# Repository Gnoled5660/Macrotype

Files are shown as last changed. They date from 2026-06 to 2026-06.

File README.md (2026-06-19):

# Macrotype
Macropad_with_Case_2026-Jun-15_12-51-55PM-000_CustomizedView37122516277_png

# Description
This is a fully custom wireless hot swappable macropad with a custom Microcontroller. It has a total of nine fully custom programmable keyswitches and a rotary encoder as well as a 0.91 OLED display. It still remains pretty compact, while having that many components. It's size is approximately 10x6.8x1.6cm. There is a LiPo 3.7V Battery built in, but if you want to charge it, you can simply charge the battery via the USB-C receptacle. The macropad has an IC charger built in. If it is connected to the USB-C port, then the nRF52840 MCU chip, will be directly powered by the external power source, while the battery is being charged. However, if it is not connected to an external power supply, then the chip will be powered by the battery.

# Motivation
I have always wanted to design my own macropad, as it can be quite useful. I wanted to challenge myself a little bit, which is why I didn't choose a regular microcontroller and designed the entire board myself. 

# Assembling the macropad
It is quite straight forward to assemble everything. As the PCB will be preassembled by JLCPCB, since there are many components that cannot be hand soldered, there is not much to do on the soldering part. It is only necessary to solder the display and the rotary encoder onto the PCB and connect the Battery with the socket. There are four mounting holes on the PCB, that are used to screw screws onto the CAD model. For this project, you only need four M2 screws. It is also recommended to use heated threat inserts, to guarentee more grip.

# Schematic and Components
The main component is the nRF52840, a relatively cheap chip, that is capable of bluetooth low energy. This chip functions as the main processing unit, to handle all the actions that can be done with the board. Another important component is the BQ24074, it is an IC charger that can charge the battery, while still letting power to the MCU. As the battery is a 3.7V LiPo, the voltage always varies between 3.3V and 4.0V. Thats why there is also a Low Dropout Regulator, that convert the voltage to 3.3V.

Bildschirmfoto 2026-06-15 um 15 30 08

Using this reference provided by nordic semiconductors, I was able to draw the schematic around the chip.

Bildschirmfoto 2026-06-19 um 12 18 31

# PCB
The PCB is a 4 layer PCB, with the first and fourth layer function as signal transmitting layers. The second layer is a big Ground plane and the third layer is a hybrid layer with signal tracks and Ground planes. The most crucial part of the PCB is the radio frequency part. This part cannot have any tracks or Ground planes above or under it, as any distrubances might change the frequency.

Bildschirmfoto 2026-06-15 um 15 33 07

Bildschirmfoto 2026-06-15 um 15 30 40

Bildschirmfoto 2026-06-17 um 20 18 41

Bildschirmfoto 2026-06-17 um 20 19 51

# Firmware 
To flash the nRF52840 chip, you have to use a bootloader and connect it physically to the pin sockets on the board. There is a row with SWD sockets. Connect it to these rows and flash the Firmware onto it. You can find it in the folder Firmware. Afterwards, you can simply connect the chip via the USB-C port to a computer and upload the uf2 file, which contains all the keyboard settings and drag the files onto the chip. The keyboard firmware was built with ZMK.

# Firmware setup
The firmware was built with ZMK. After following the guide of ZMK of how to setup your own ZMK configuration GitHub repo, you have to change the board informations according to your needs. My custom Macropad includes having a rotary encoder, display and a 3x3 Matrix switches. You can find the configurations in detail in the ZMK config file.

# Case
The case consists of two different parts. The bottom part has four holes, where heated threat inserts can be inserted. There is a rectangle that stands out a little bit, so that it can be pressed in to the other part.

Bildschirmfoto 2026-06-17 um 23 51 36

Bildschirmfoto 2026-06-17 um 23 53 58

Copy of fallout_zine_template-7

# BOM
|Reference |Qty |Links |Value|Footprint|Description |Price |
|---|---|---|-----|---|---|---|
|Crystal |1 |https://jlcpcb.com |32.768kHz|Crystal:Crystal_SMD_3215-2Pin_3.2x1.5mm|Two pin crystal  |See below|
|Crystal |1 |https://jlcpcb.com |32MHz|Crystal:Crystal_SMD_2016-4Pin_2.0x1.6mm|Two pin crystal  |See below|
|Low Dropout Regulator|1 |https://jlcpcb.com |MCP1700T-3302E_TT|MCP1700T-3302E_TT:SOT95P237X112-3N|Pwr Sply Func,Voltage Regulator,LDO,SOT-23,PD 369.6mW,VO 3.3V,Regline +/-0.75%/V &#124; Microchip Technology Inc. MCP1700T-3302E/TT|See below|
|IC Charger |1 |https://jlcpcb.com |BQ24074RGTR|BQ24074RGTR:QFN50P300X300X100-17N|Standalone 1-cell 1.5-A linear battery charger, Power Path, 4.2-V VBAT, 10.5-V OVP and 4.4-V VOUT|See below|
|nRF52840 |1 |https://jlcpcb.com |NRF52840-QIAA-R|footprints:AQFN-73-1EP_7x7mm_P0.5mm_NRF52840-custom|IC RF TxRx + MCU 802.15.4, Bluetooth Bluetooth v5.0, Thread, Zigbee® 2.4GHz 73-VFQFN Dual Rows, Exposed Pad|See below|
|Rotary Encoder |1 |https://jlcpcb.com |RotaryEncoder_Switch|Rotary_Encoder:RotaryEncoder_Alps_EC11E-Switch_Vertical_H20mm|Rotary encoder, dual channel, incremental quadrate outputs, with switch|See below|
|Button |1 |https://jlcpcb.com |SW_Push|Button_Switch_SMD:SW_Push_1P1T_NO_CK_KMR2|Push button switch, generic, two pins|See below|
|Keyswitch |9 |https://jlcpcb.com |Keyswitch|Switch_Keyboard_Hotswap_Kailh:SW_Hotswap_Kailh_MX|Push button switch, normally open, two pins, 45° tilted|See below|
|Resistor |2 |https://jlcpcb.com |5.1k |Resistor_SMD:R_0402_1005Metric|Resistor |See below|
|Resistor |3 |https://jlcpcb.com |10k  |Resistor_SMD:R_0402_1005Metric|Resistor |See below|
|Resistor |1 |https://jlcpcb.com |47k  |Resistor_SMD:R_0402_1005Metric|Resistor |See below|
|Resistor |1 |https://jlcpcb.com |0 |Resistor_SMD:R_0402_1005Metric|Resistor |See below|
|Resistor |1 |https://jlcpcb.com |5.9k |Resistor_SMD:R_0402_1005Metric|Resistor |See below|
|Resistor |1 |https://jlcpcb.com |3.0k |Resistor_SMD:R_0402_1005Metric|Resistor |See below|
|Resistor |2 |https://jlcpcb.com |1.5k |Resistor_SMD:R_0402_1005Metric|Resistor |See below|
|Inductor |1 |https://jlcpcb.com |4.7nH|Inductor_SMD:L_0402_1005Metric|Inductor |See below|
|USB-C Receptacle |1 |https://jlcpcb.com |TYPE-C-31-M-12|TYPE-C-31-M-12:HRO_TYPE-C-31-M-12|USB Connectors 24 Receptacle 1 8.94*7.3mm RoHS|See below|
|JST Socket |1 |https://jlcpcb.com |Conn_01x02_Socket|Connector_JST:JST_PH_S2B-PH-K_1x02_P2.00mm_Horizontal|Generic connector, single row, 01x02, script generated|See below|
|LED |2 |https://jlcpcb.com |LED  |LED_SMD:LED_0603_1608Metric|Light emitting diode|See below|
|Unpolarized Capcitor|1 |https://jlcpcb.com |820pF|Capacitor_SMD:C_0402_1005Metric|Unpolarized capacitor|See below|
|Unpolarized Capcitor|1 |https://jlcpcb.com |1.5pF|Capacitor_SMD:C_0402_1005Metric|Unpolarized capacitor|See below|
|Unpolarized Capcitor|1 |https://jlcpcb.com |0.5pF|Capacitor_SMD:C_0402_1005Metric|Unpolarized capacitor|See below|
|Unpolarized Capcitor|1 |https://jlcpcb.com |0.8pF|Capacitor_SMD:C_0402_1005Metric|Unpolarized capacitor|See below|
|Unpolarized Capcitor|1 |https://jlcpcb.com |100pF|Capacitor_SMD:C_0402_1005Metric|Unpolarized capacitor|See below|
|Unpolarized Capcitor|2 |https://jlcpcb.com |N.C. |Capacitor_SMD:C_0402_1005Metric|Unpolarized capacitor|See below|
|Unpolarized Capcitor|1 |https://jlcpcb.com |1.0uF|Capacitor_SMD:C_0603_1608Metric|Unpolarized capacitor|See below|
|Unpolarized Capcitor|4 |https://jlcpcb.com |1uF  |Capacitor_SMD:C_0603_1608Metric|Unpolarized capacitor|See below|
|Unpolarized Capcitor|3 |https://jlcpcb.com |100nF|Capacitor_SMD:C_0402_1005Metric|Unpolarized capacitor|See below|
|Unpolarized Capcitor|4 |https://jlcpcb.com |12pF |Capacitor_SMD:C_0402_1005Metric|Unpolarized capacitor|See below|
|Unpolarized Capcitor|4 |https://jlcpcb.com |4.7uF|Capacitor_SMD:C_0603_1608Metric|Unpolarized capacitor|See below|
|0.91 Display |1 |https://www.roboter-bausatz.de/p/0.91-oled-display-blau-128-32-ssd1306-i2c-modul-fuer-arduino-raspberry-pi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 | | |Oled Display 128x32|4 |
|Hot Swappable Sockets|50 |https://amazon.com | | |Kailh CPG151101S11 Hot Swappable PCB Socket|10 |
|PCB with all Components|1 |https://jlcpcb.com | | |5x PCB fully assembled|110 |
|Filament | | | | | 40g | 0.5 |
|total | | | | | |124 |

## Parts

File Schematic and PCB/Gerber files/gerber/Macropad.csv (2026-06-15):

Id | Designator | Footprint | Quantity | Designation | Supplier and ref
1 |  |  | 1
2 | C1, C17, C19, C20 | C_0603_1608Metric | 4 | 4.7uF
3 | C2, C3, C11, C12 | C_0402_1005Metric | 4 | 12pF
4 | C4, C10, C23 | C_0402_1005Metric | 3 | 100nF
5 | C5, C18, C21, C22 | C_0603_1608Metric | 4 | 1uF
6 | C6 | C_0603_1608Metric | 1 | 1.0uF
7 | C7, C9 | C_0402_1005Metric | 2 | N.C.
8 | C8 | C_0402_1005Metric | 1 | 100pF
9 | C13 | C_0402_1005Metric | 1 | 0.8pF
10 | C14 | C_0402_1005Metric | 1 | 0.5pF
11 | C15 | C_0402_1005Metric | 1 | 1.5pF
12 | C16 | C_0402_1005Metric | 1 | 820pF
13 | D10, D11 | LED_0603_1608Metric | 2 | LED
14 | Display1 | PinHeader_1x04_P2.54mm_Vertical | 1 | Conn_01x04_Socket
15 | J1 | JST_PH_S2B-PH-K_1x02_P2.00mm_Horizontal | 1 | Conn_01x02_Socket
16 | J2 | HRO_TYPE-C-31-M-12 | 1 | TYPE-C-31-M-12
17 | L1 | L_0402_1005Metric | 1 | 4.7nH
18 | MCU_flash1 | PinHeader_1x05_P2.54mm_Vertical | 1 | Conn_01x05_Socket
19 | R1, R2 | R_0402_1005Metric | 2 | 1.5k
20 | R3 | R_0402_1005Metric | 1 | 3.0k
21 | R4 | R_0402_1005Metric | 1 | 5.9k
22 | R5 | R_0402_1005Metric | 1 | 0
23 | R6 | R_0402_1005Metric | 1 | 47k
24 | R7, R9, R10 | R_0402_1005Metric | 3 | 10k
25 | R11, R12 | R_0402_1005Metric | 2 | 5.1k
26 | SW1, SW2, SW3, SW4, SW5, SW6, SW7, SW8, SW9 | SW_Hotswap_Kailh_MX | 9 | Keyswitch
27 | SW10 | SW_Push_1P1T_NO_CK_KMR2 | 1 | SW_Push
28 | SW11 | RotaryEncoder_Alps_EC11E-Switch_Vertical_H20mm | 1 | RotaryEncoder_Switch
29 | U1 | AQFN-73-1EP_7x7mm_P0.5mm_NRF52840-custom | 1 | NRF52840-QIAA-R
30 | U2 | QFN50P300X300X100-17N | 1 | BQ24074RGTR
31 | VR1 | SOT95P237X112-3N | 1 | MCP1700T-3302E_TT
32 | X1 | Crystal_SMD_2016-4Pin_2.0x1.6mm | 1 | 32MHz
33 | X2 | Crystal_SMD_3215-2Pin_3.2x1.5mm | 1 | 32.768kHz

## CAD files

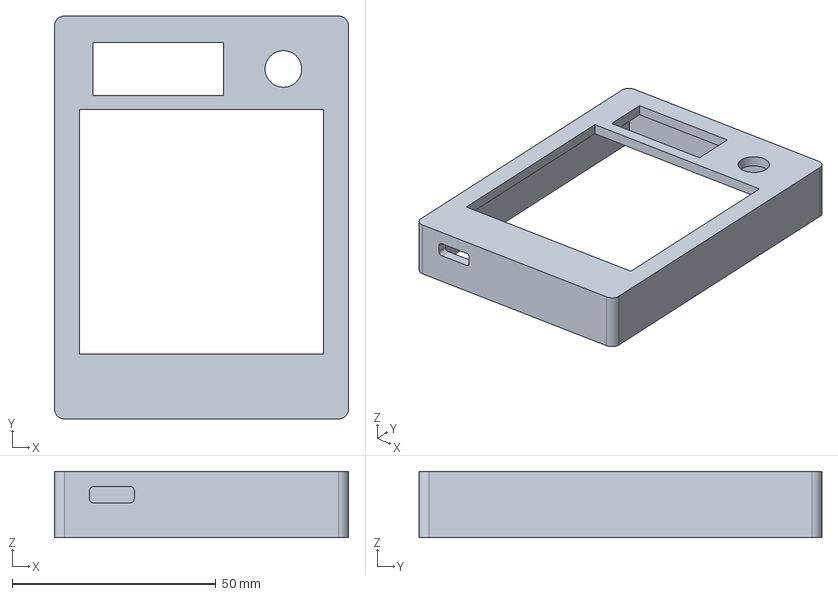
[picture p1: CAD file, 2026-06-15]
CAD/Case Top.step
72.2 x 98.9 x 16.2 mm

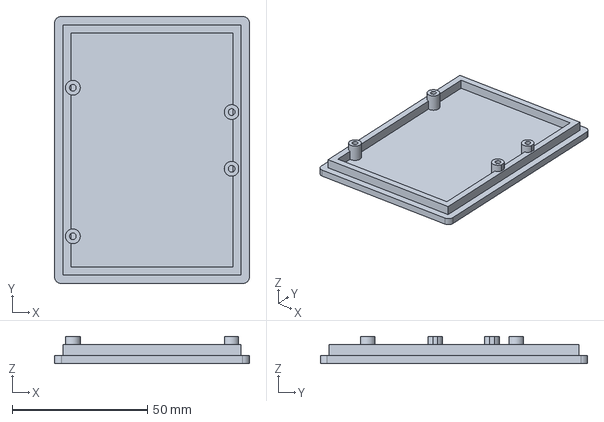
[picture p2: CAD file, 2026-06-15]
CAD/Case bottom.step
72.2 x 98.9 x 10.1 mm

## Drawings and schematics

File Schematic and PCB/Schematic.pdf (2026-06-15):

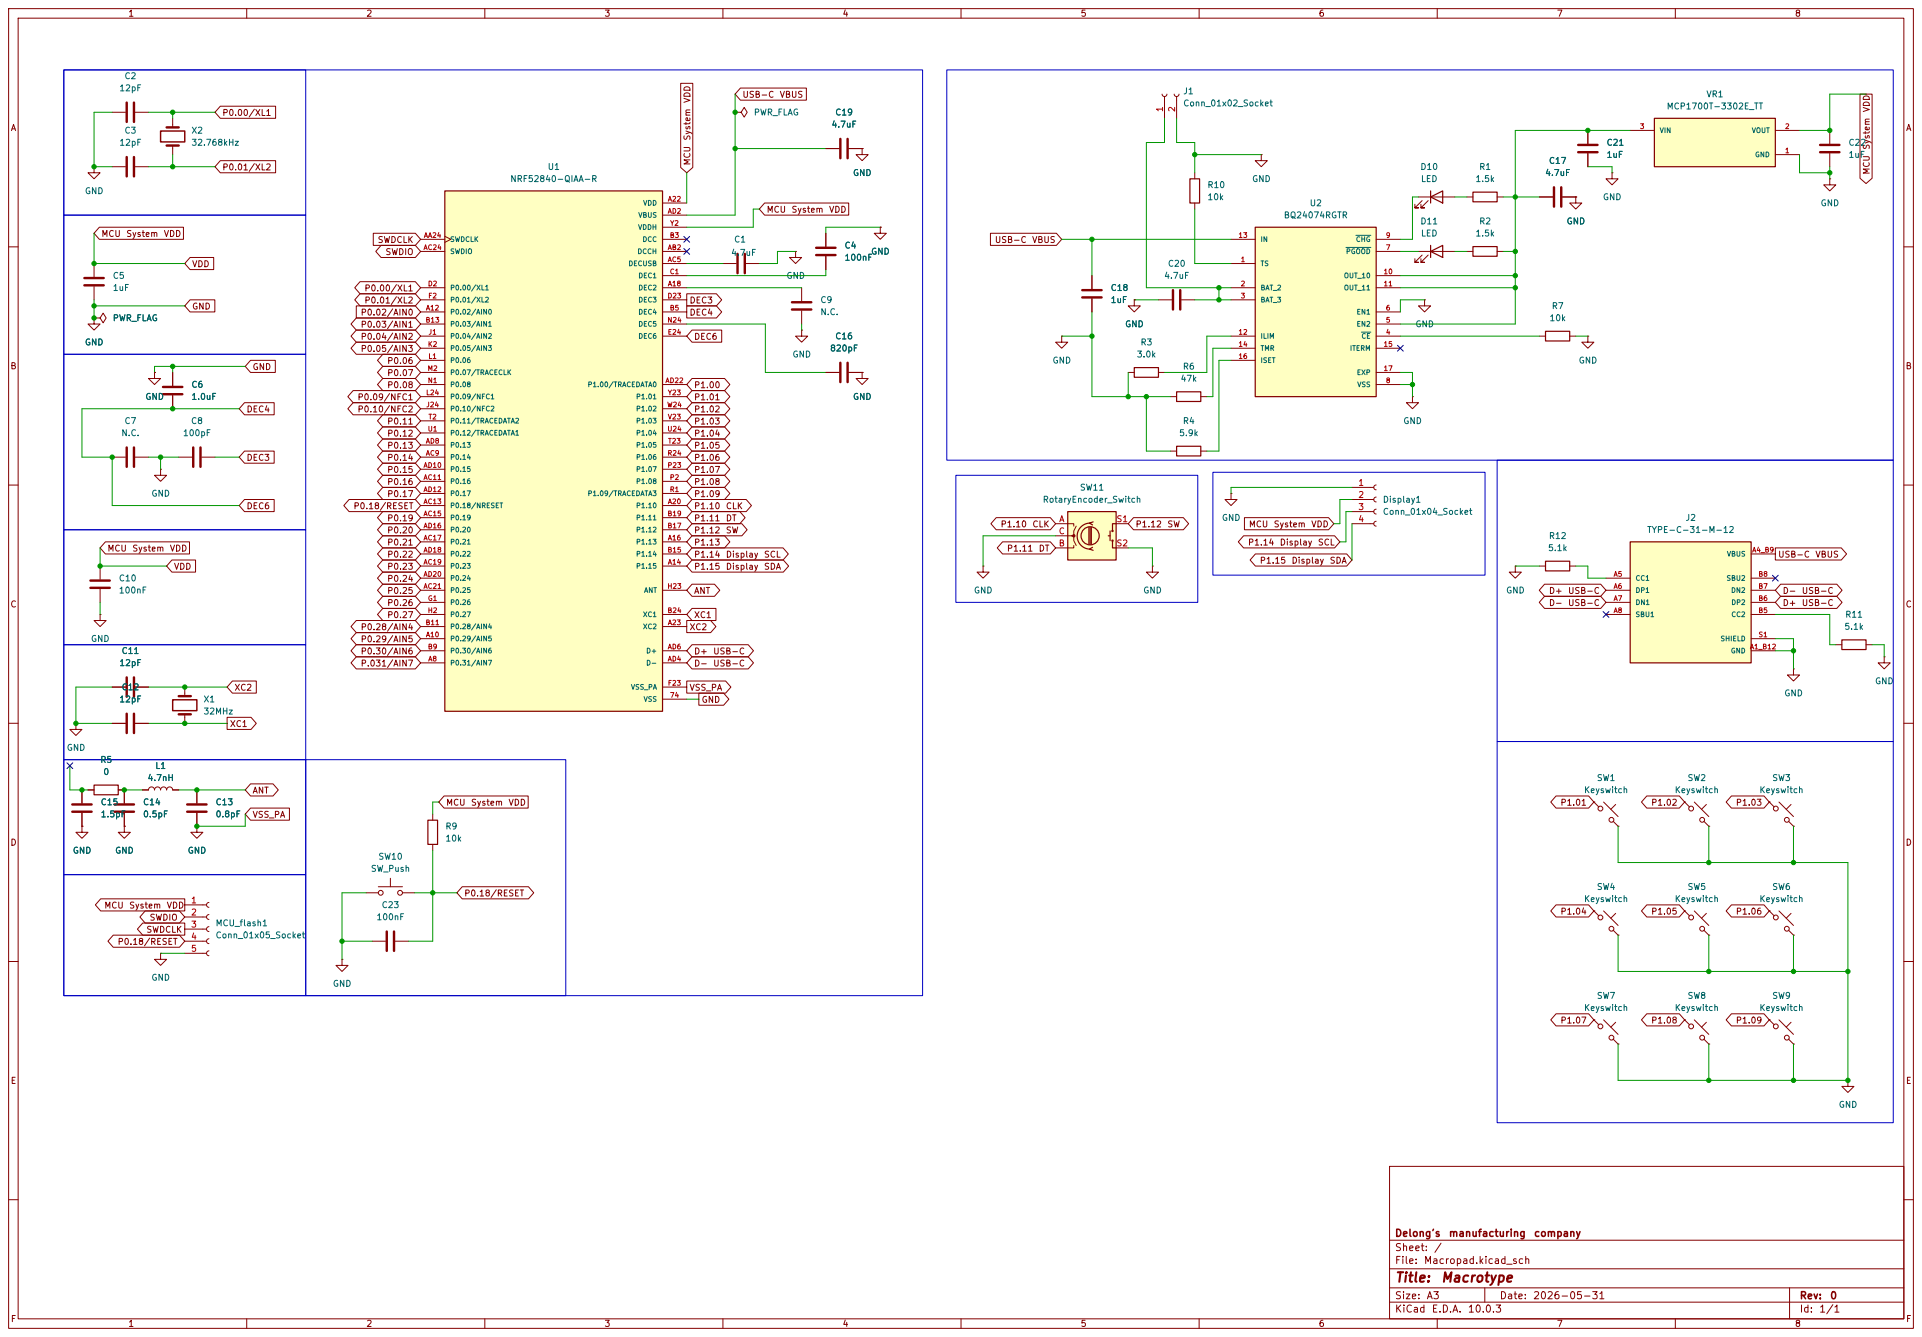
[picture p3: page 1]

P1.14 Display SCL VSS_PA MCU System VDD

12pF C8
SWDCLK MCU System VDD MCU System VDD 12pF C12

0.5pF | 32MHz C13 C13 0.8pF GND 0.8pF GND | GND SW_Push R9

Size: A3 | Rev: 0 | F Date: 2026-05-31
KiCad E.D.A. 10.0.3 | Id: 1/1

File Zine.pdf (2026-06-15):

# Macrotype

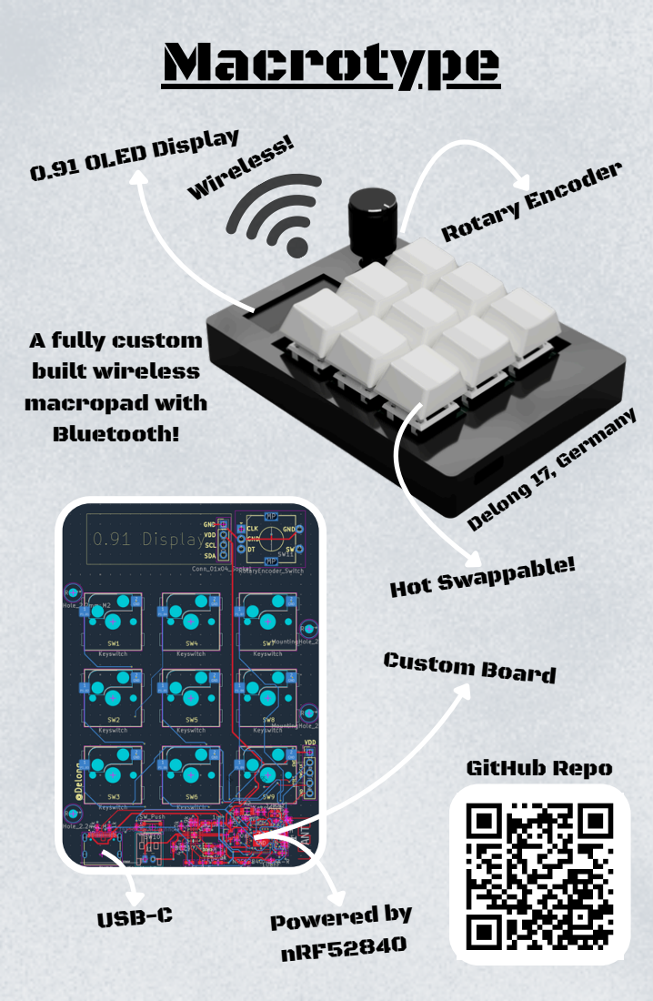
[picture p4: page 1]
Delong 17, Germany; Hot Swappable!; GitHub Repo; Wireless!; Rotary Encoder; LED Display; A fully custom built wireless macropad with Bluetooth!; Custom Board; Powered by nRF52840; USB-C

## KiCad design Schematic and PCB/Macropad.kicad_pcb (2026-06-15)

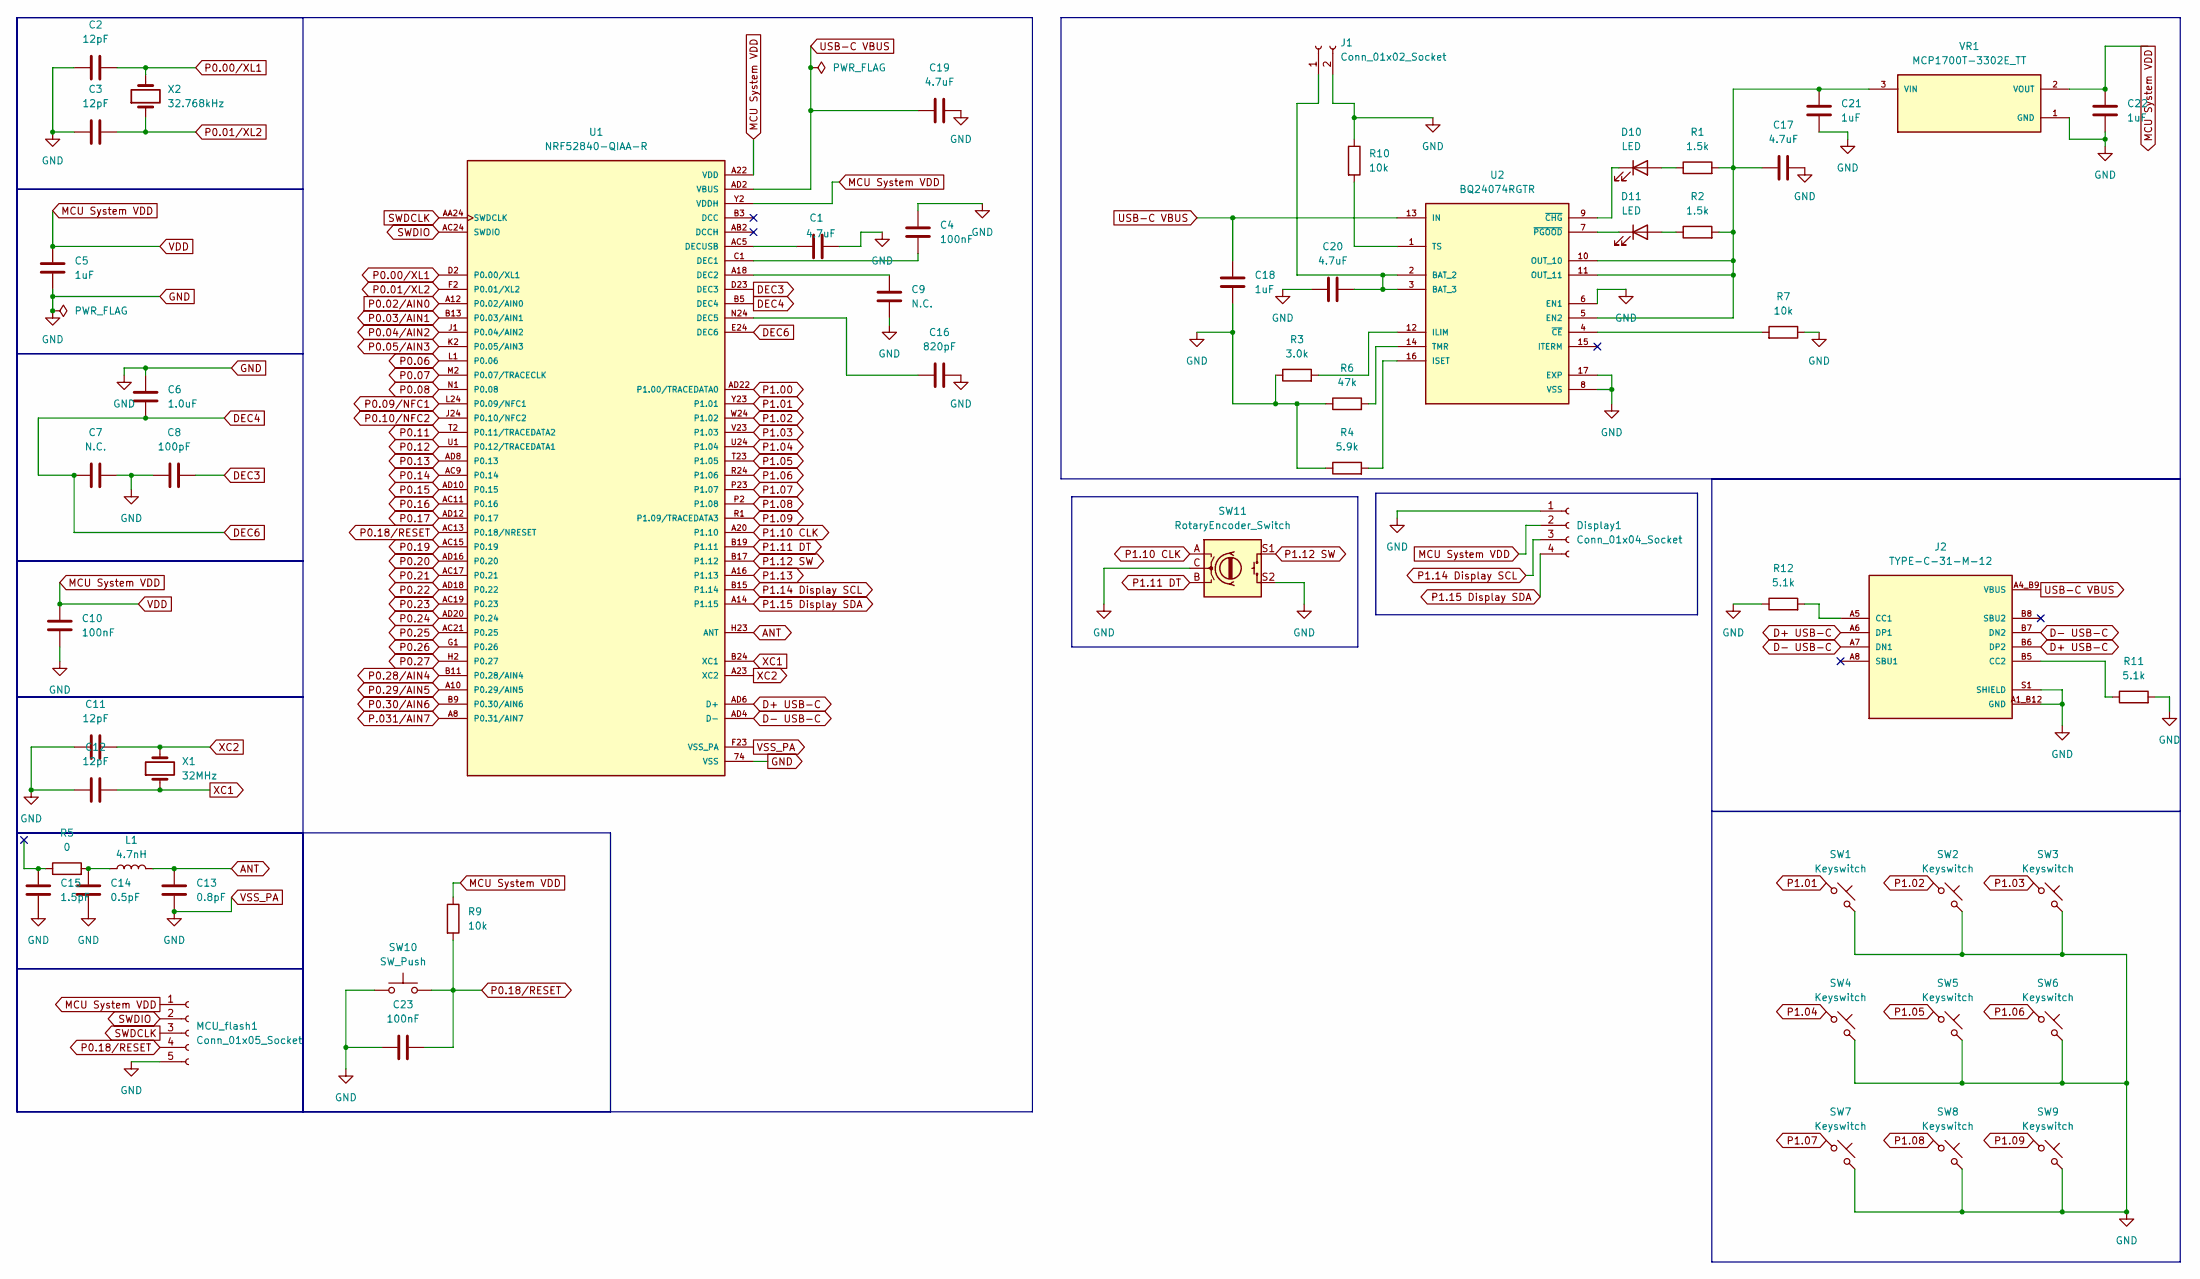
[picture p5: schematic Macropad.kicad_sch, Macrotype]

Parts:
C1, C17, C19, C20: 4.7uF; C_0603_1608Metric
C2, C3, C11, C12: 12pF; C_0402_1005Metric
C4, C10, C23: 100nF; C_0402_1005Metric
C5, C18, C21, C22: 1uF; C_0603_1608Metric
C6: 1.0uF; C_0603_1608Metric
C7, C9: N.C.; C_0402_1005Metric
C8: 100pF; C_0402_1005Metric
C13: 0.8pF; C_0402_1005Metric
C14: 0.5pF; C_0402_1005Metric
C15: 1.5pF; C_0402_1005Metric
C16: 820pF; C_0402_1005Metric
D10, D11: LED; LED_0603_1608Metric
Display1: Conn_01x04_Socket; PinHeader_1x04_P2.54mm_Vertical
J1: Conn_01x02_Socket; JST_PH_S2B-PH-K_1x02_P2.00mm_Horizontal
J2: TYPE-C-31-M-12; HRO_TYPE-C-31-M-12; PARTREV 2020.12.08
L1: 4.7nH; L_0402_1005Metric
MCU_flash1: Conn_01x05_Socket; PinHeader_1x05_P2.54mm_Vertical
R1, R2: 1.5k; R_0402_1005Metric
R3: 3.0k; R_0402_1005Metric
R4: 5.9k; R_0402_1005Metric
R5: 0; R_0402_1005Metric
R6: 47k; R_0402_1005Metric
R7, R9, R10: 10k; R_0402_1005Metric
R11, R12: 5.1k; R_0402_1005Metric
SW1, SW2, SW3, SW4, SW5, SW6, SW7, SW8, SW9: Keyswitch; SW_Hotswap_Kailh_MX
SW10: SW_Push; SW_Push_1P1T_NO_CK_KMR2
SW11: RotaryEncoder_Switch; RotaryEncoder_Alps_EC11E-Switch_Vertical_H20mm
U1: NRF52840-QIAA-R; AQFN-73-1EP_7x7mm_P0.5mm_NRF52840-custom; PARTREV v1.1
U2: BQ24074RGTR; QFN50P300X300X100-17N; PARTREV M
VR1: MCP1700T-3302E_TT; SOT95P237X112-3N; PARTREV E
X1: 32MHz; Crystal_SMD_2016-4Pin_2.0x1.6mm
X2: 32.768kHz; Crystal_SMD_3215-2Pin_3.2x1.5mm

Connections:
/ANT: C15.1, R5.1
ANT: C13.1, L1.2, U1.H23 (ANT)
D+ USB-C: J2.A6 (DP1), J2.B6 (DP2), U1.AD6 (D+)
D- USB-C: J2.A7 (DN1), J2.B7 (DN2), U1.AD4 (D-)
DEC3: C8.2, U1.D23 (DEC3)
DEC4: C6.2, C7.1, U1.B5 (DEC4), U1.E24 (DEC6)
GND: C1.2, C2.1, C3.1, C4.1, C5.2, C6.1, C7.2, C8.1, C9.2, C10.2, C11.1, C12.1, C13.2, C14.2, C15.2, C16.1, C17.2, C18.2, C19.2, C20.1, C21.1, C22.2, C23.1, Display1.1, J1.2, J2.A1_B12 (GND), J2.B1_A12 (GND), J2.S1 (SHIELD), J2.S2 (SHIELD), J2.S3 (SHIELD), J2.S4 (SHIELD), MCU_flash1.5, R3.1, R4.1, R6.1, R7.1, R10.1, R11.2, R12.1, SW1.2, SW2.2, SW3.2, SW4.2, SW5.2, SW6.2, SW7.2, SW8.2, SW9.2, SW10.1, SW11.C, SW11.S2, U1.74 (VSS), U1.B7 (VSS), U1.F23 (VSS_PA), U2.6 (EN1), U2.8 (VSS), U2.17 (EXP), U2.18, U2.19, U2.20, U2.21, U2.22, VR1.1 (GND)
MCU System VDD: C5.1, C10.1, C22.1, Display1.2, MCU_flash1.1, R9.1, U1.A22 (VDD), U1.AD14 (VDD), U1.AD23 (VDD), U1.B1 (VDD), U1.W1 (VDD), U1.Y2 (VDDH), VR1.2 (VOUT)
unnamed: C14.1, L1.1, R5.2
unnamed: D10.2 (A), R1.1
unnamed: D10.1 (K), U2.9 (~CHG)
unnamed: D11.2 (A), R2.1
unnamed: D11.1 (K), U2.7 (~PGOOD)
unnamed: C20.2, J1.1, U2.2 (BAT_2), U2.3 (BAT_3)
unnamed: J2.A5 (CC1), R12.2
unnamed: J2.B5 (CC2), R11.1
unnamed: C4.2, U1.C1 (DEC1)
unnamed: C9.1, U1.A18 (DEC2)
unnamed: C16.2, U1.N24 (DEC5)
unnamed: C1.1, U1.AC5 (DECUSB)
unnamed: C17.1, C21.2, R1.2, R2.2, U2.5 (EN2), U2.10 (OUT_10), U2.11 (OUT_11), VR1.3 (VIN)
unnamed: R3.2, U2.12 (ILIM)
unnamed: R4.2, U2.16 (ISET)
unnamed: R6.2, U2.14 (TMR)
unnamed: R10.2, U2.1 (TS)
unnamed: R7.2, U2.4 (~CE)
P0.00/XL1: C2.2, U1.D2 (P0.00/XL1), X2.2
P0.01/XL2: C3.2, U1.F2 (P0.01/XL2), X2.1
P0.02/AIN0: U1.A12 (P0.02/AIN0)
P0.03/AIN1: U1.B13 (P0.03/AIN1)
P0.04/AIN2: U1.J1 (P0.04/AIN2)
P0.05/AIN3: U1.K2 (P0.05/AIN3)
P0.06: U1.L1 (P0.06)
P0.07: U1.M2 (P0.07/TRACECLK)
P0.08: U1.N1 (P0.08)
P0.09/NFC1: U1.L24 (P0.09/NFC1)
P0.10/NFC2: U1.J24 (P0.10/NFC2)
P0.11: U1.T2 (P0.11/TRACEDATA2)
P0.12: U1.U1 (P0.12/TRACEDATA1)
P0.13: U1.AD8 (P0.13)
P0.14: U1.AC9 (P0.14)
P0.15: U1.AD10 (P0.15)
P0.16: U1.AC11 (P0.16)
P0.17: U1.AD12 (P0.17)
P0.18/RESET: C23.2, MCU_flash1.4, R9.2, SW10.2, U1.AC13 (P0.18/NRESET)
P0.19: U1.AC15 (P0.19)
P0.20: U1.AD16 (P0.20)
P0.21: U1.AC17 (P0.21)
P0.22: U1.AD18 (P0.22)
P0.23: U1.AC19 (P0.23)
P0.24: U1.AD20 (P0.24)
P0.25: U1.AC21 (P0.25)
P0.26: U1.G1 (P0.26)
P0.27: U1.H2 (P0.27)
P0.28/AIN4: U1.B11 (P0.28/AIN4)
P0.29/AIN5: U1.A10 (P0.29/AIN5)
P0.30/AIN6: U1.B9 (P0.30/AIN6)
P1.00: U1.AD22 (P1.00/TRACEDATA0)
P1.01: SW1.1, U1.Y23 (P1.01)
P1.02: SW2.1, U1.W24 (P1.02)
P1.03: SW3.1, U1.V23 (P1.03)
P1.04: SW4.1, U1.U24 (P1.04)
P1.05: SW5.1, U1.T23 (P1.05)
P1.06: SW6.1, U1.R24 (P1.06)
P1.07: SW7.1, U1.P23 (P1.07)
P1.08: SW8.1, U1.P2 (P1.08)
P1.09: SW9.1, U1.R1 (P1.09/TRACEDATA3)
P1.10 CLK: SW11.A, U1.A20 (P1.10)
P1.11 DT: SW11.B, U1.B19 (P1.11)
P1.12 SW: SW11.S1, U1.B17 (P1.12)
P1.13: U1.A16 (P1.13)
P1.14 Display SCL: Display1.3, U1.B15 (P1.14)
P1.15 Display SDA: Display1.4, U1.A14 (P1.15)
P.031/AIN7: U1.A8 (P0.31/AIN7)
SWDCLK: MCU_flash1.3, U1.AA24 (SWDCLK)
SWDIO: MCU_flash1.2, U1.AC24 (SWDIO)
USB-C VBUS: C18.1, C19.1, J2.A4_B9 (VBUS), J2.B4_A9 (VBUS), U1.AD2 (VBUS), U2.13 (IN)
XC1: C12.2, U1.B24 (XC1), X1.1
XC2: C11.2, U1.A23 (XC2), X1.2

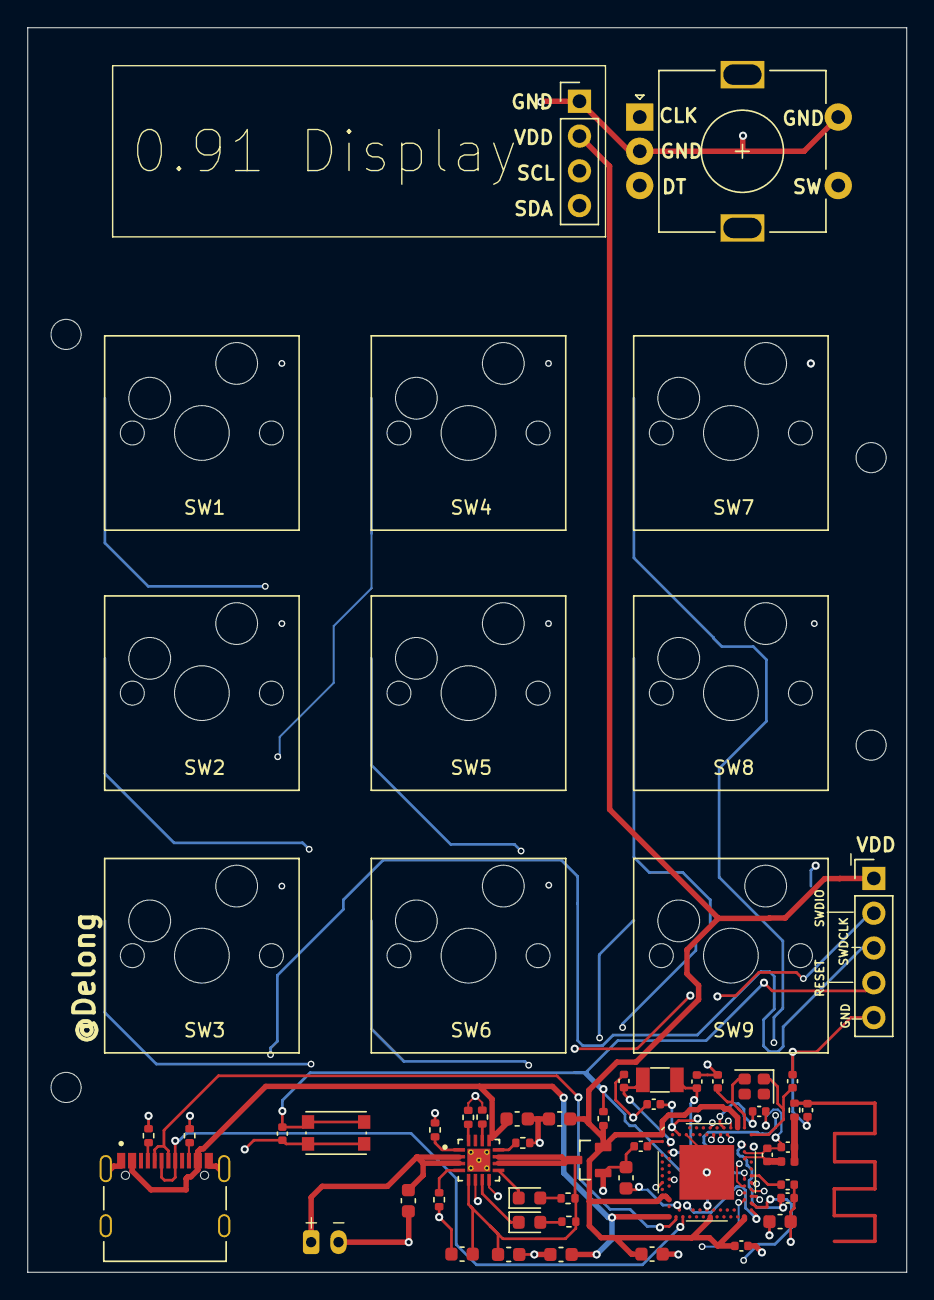
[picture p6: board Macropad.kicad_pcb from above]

Board: 4 copper layers, 64.2 x 90.9 mm, 57 parts (1 on the bottom side), 48 nets.

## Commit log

2026-06-15 Update and rename Macropad - Macropad.csv.csv to BOM.csv
    [BOM.csv]
2026-06-17 Add BOM section to README.md
    Added a Bill of Materials (BOM) section with component details and links.
